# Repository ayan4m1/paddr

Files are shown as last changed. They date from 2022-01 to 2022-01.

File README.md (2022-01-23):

# Paddr

Paddr is a DIY numpad built using [KMK](https://github.com/KMKfw/kmk_firmware). It has four RGB LEDs and seventeen keys.

## Schematic

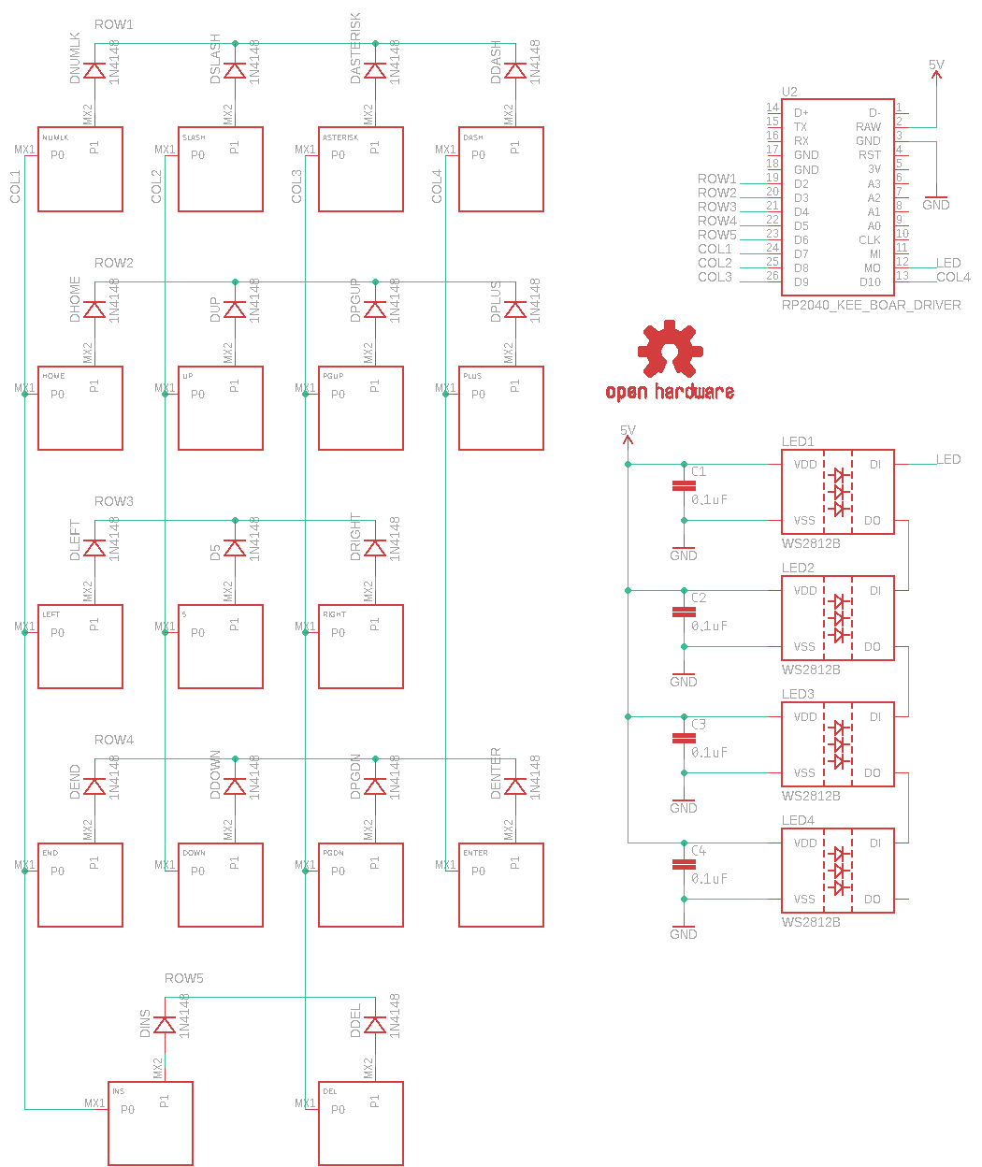
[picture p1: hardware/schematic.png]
schematic


## Board

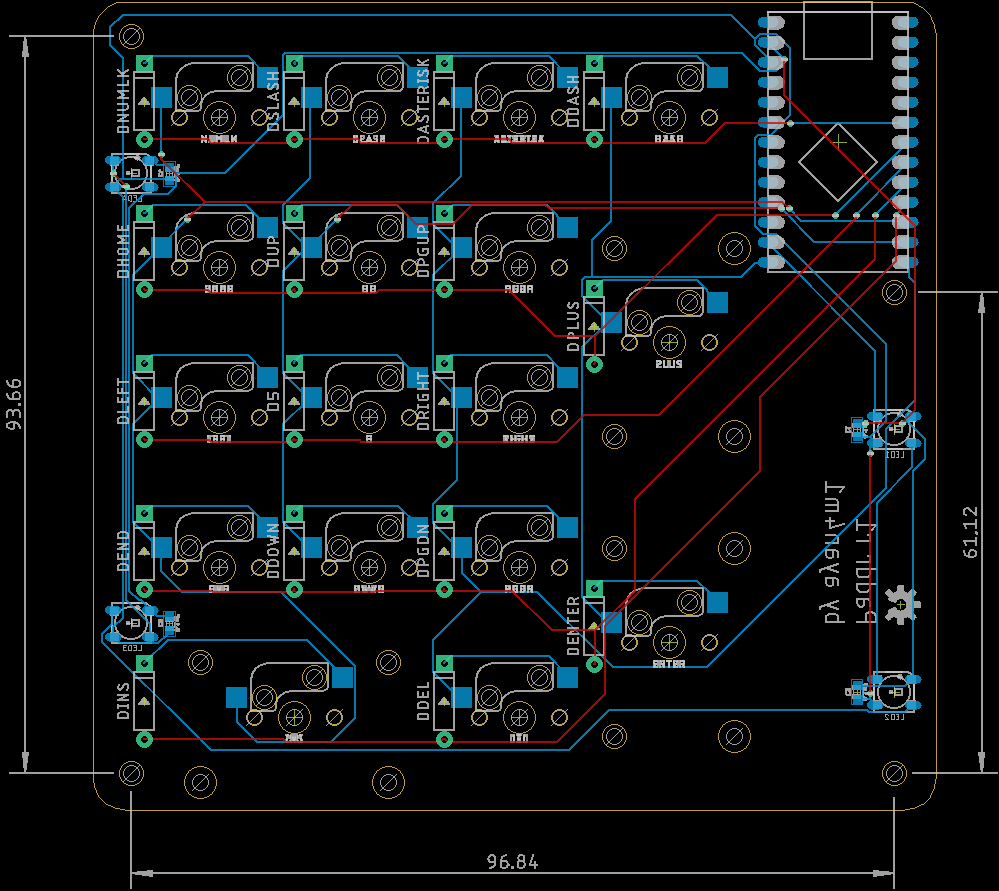
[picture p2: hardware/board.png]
board


## PCB

[OSH Park](https://oshpark.com/shared_projects/GSJlJusC)

## BOM

| Vendor | Part | Quantity |
| --- | --- | --- |
| onsemi | [1N4148 Diode](https://www.mouser.com/ProductDetail/onsemi-Fairchild/1N4148?qs=i4Fj9T%2FoRm8RMUhj5DeFQg%3D%3D) | 17 |
| Kailh | [Hotswap Sockets](https://shop.keyboard.io/products/kailh-hotswap-sockets-for-mx-style-keyswitches-x-25) | 17 |
| Adafruit  | [KB2040](https://www.adafruit.com/product/5302) | 1 |
| Worldsemi | [WS2812B](https://www.adafruit.com/product/1655) | 4 |
| Samsung | [0.1uF 6.3V Capacitor - 0603](https://www.mouser.com/ProductDetail/Samsung-Electro-Mechanics/CL03A105MQ3CSNH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) | 4 |

## Assembly

1. Solder the capacitors and LEDs to the bottom of the board.
2. Solder the hotswap sockets to the bottom of the board.
3. Solder the diodes to the top of the board.
4. Solder the KB2040 to the bottom of the board.

## Firmware

Copy all files from the firmware directory to the root of the CIRCUITPY drive. The keymap lives in code.py.

After you install the firmware, the CIRCUITPY drive and USB serial port will be hidden on subsequent restarts of the numpad. To override this behavior, hold down the dash key while plugging the numpad in.

To configure the RGB, double tap the zero key, then tap one of the following buttons:

| Key | RGB Function |
| --- | --- |
| 5 | Toggle On/Off  |
| 8 | Value Increase |
| 2 | Value Decrease |
| 4 | Hue Decrease |
| 6 | Hue Increase |
| NumLk | Mode - Solid |
| Slash | Mode - Breathe |
| Asterisk | Mode - Rainbow |
| Dash | Mode - Swirl |

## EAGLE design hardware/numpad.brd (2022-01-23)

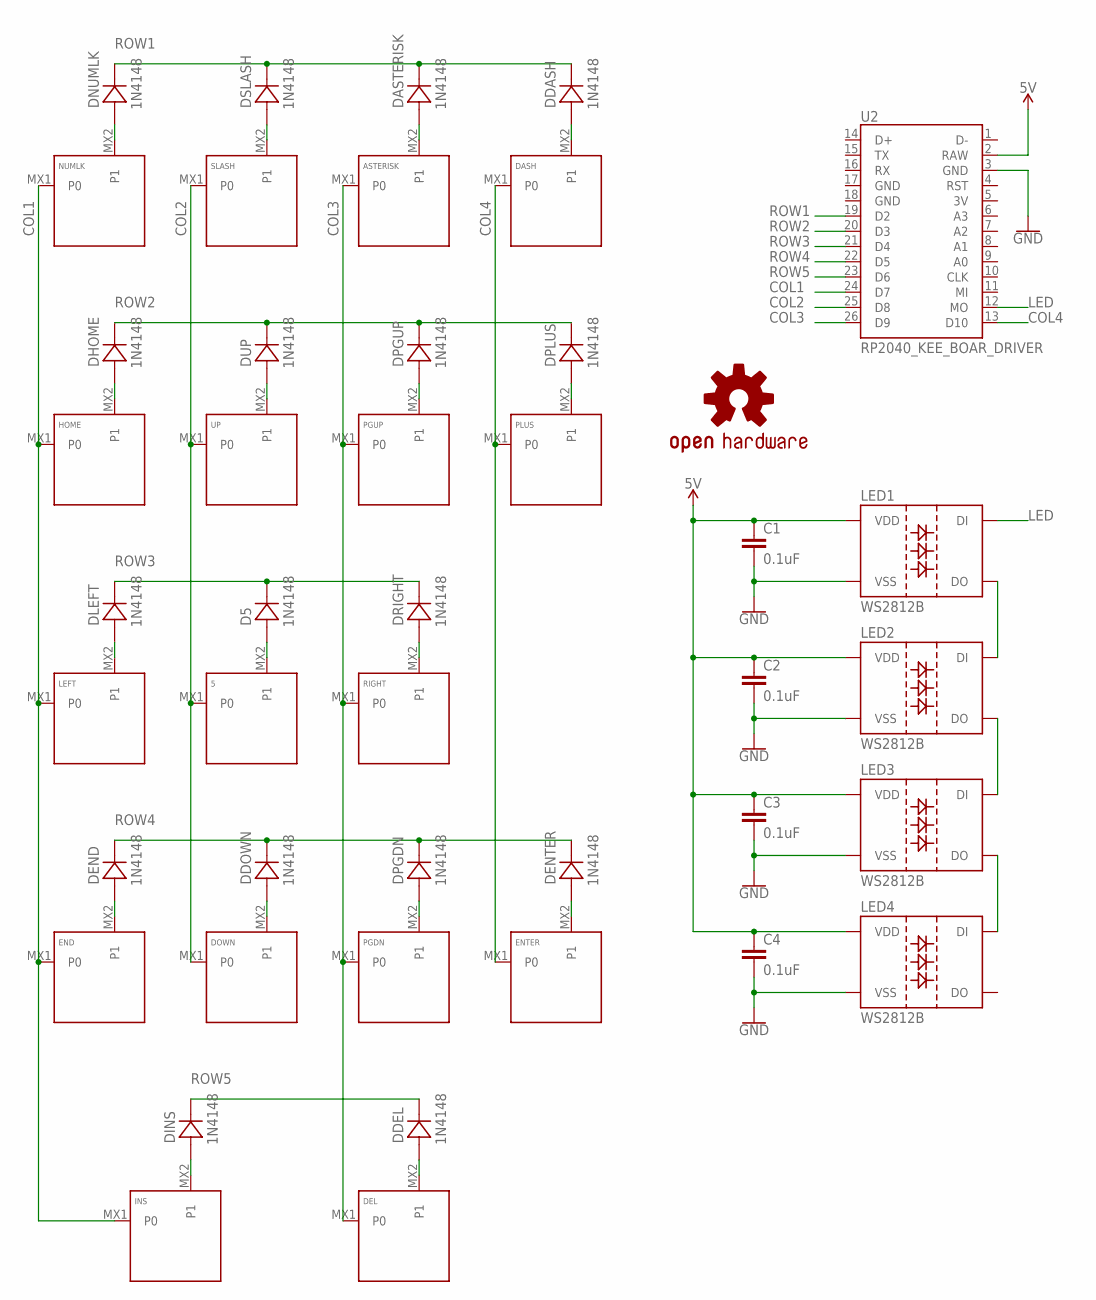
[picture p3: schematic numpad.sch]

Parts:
5: KEYSWITCH-PLAIN-MXHSPCB-1U; MXHSPCB-1U
ASTERISK: KEYSWITCH-PLAIN-MXHSPCB-1U; MXHSPCB-1U
C1, C2, C3, C4: 0.1uF; 0603
D5: 1N4148; DO-35
DASH: KEYSWITCH-PLAIN-MXHSPCB-1U; MXHSPCB-1U
DASTERISK: 1N4148; DO-35
DDASH: 1N4148; DO-35
DDEL: 1N4148; DO-35
DDOWN: 1N4148; DO-35
DEL: KEYSWITCH-PLAIN-MXHSPCB-1U; MXHSPCB-1U
DEND: 1N4148; DO-35
DENTER: 1N4148; DO-35
DHOME: 1N4148; DO-35
DINS: 1N4148; DO-35
DLEFT: 1N4148; DO-35
DNUMLK: 1N4148; DO-35
DOWN: KEYSWITCH-PLAIN-MXHSPCB-1U; MXHSPCB-1U
DPGDN: 1N4148; DO-35
DPGUP: 1N4148; DO-35
DPLUS: 1N4148; DO-35
DRIGHT: 1N4148; DO-35
DSLASH: 1N4148; DO-35
DUP: 1N4148; DO-35
END: KEYSWITCH-PLAIN-MXHSPCB-1U; MXHSPCB-1U
ENTER: KEYSWITCH-PLAIN-MXHSPCB-2U-ROTATED; MXHSPCB-2U-ROTATED
HOME: KEYSWITCH-PLAIN-MXHSPCB-1U; MXHSPCB-1U
INS: KEYSWITCH-PLAIN-MXHSPCB-2U; MXHSPCB-2U
LED1, LED2, LED3, LED4: WS2812B
LEFT: KEYSWITCH-PLAIN-MXHSPCB-1U; MXHSPCB-1U
LOGO1: OSHW-LOGOM; OSHW-LOGO-M
NUMLK: KEYSWITCH-PLAIN-MXHSPCB-1U; MXHSPCB-1U
PGDN: KEYSWITCH-PLAIN-MXHSPCB-1U; MXHSPCB-1U
PGUP: KEYSWITCH-PLAIN-MXHSPCB-1U; MXHSPCB-1U
PLUS: KEYSWITCH-PLAIN-MXHSPCB-2U-ROTATED; MXHSPCB-2U-ROTATED
RIGHT: KEYSWITCH-PLAIN-MXHSPCB-1U; MXHSPCB-1U
SLASH: KEYSWITCH-PLAIN-MXHSPCB-1U; MXHSPCB-1U
U2: RP2040_KEE_BOAR_DRIVER
UP: KEYSWITCH-PLAIN-MXHSPCB-1U; MXHSPCB-1U

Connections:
5V: C1.1, C2.1, C3.1, C4.1, LED1.1 (VDD), LED2.1 (VDD), LED3.1 (VDD), LED4.1 (VDD), U2.2 (RAW)
COL1: END.MX1 (P0), HOME.MX1 (P0), INS.MX1 (P0), LEFT.MX1 (P0), NUMLK.MX1 (P0), U2.24 (D7)
COL2: 5.MX1 (P0), DOWN.MX1 (P0), SLASH.MX1 (P0), U2.25 (D8), UP.MX1 (P0)
COL3: ASTERISK.MX1 (P0), DEL.MX1 (P0), PGDN.MX1 (P0), PGUP.MX1 (P0), RIGHT.MX1 (P0), U2.26 (D9)
COL4: DASH.MX1 (P0), ENTER.MX1 (P0), PLUS.MX1 (P0), U2.13 (D10)
GND: C1.2, C2.2, C3.2, C4.2, LED1.3 (VSS), LED2.3 (VSS), LED3.3 (VSS), LED4.3 (VSS), U2.3 (GND)
LED: LED1.4 (DI), U2.12 (MO)
unnamed: DNUMLK.A, NUMLK.MX2 (P1)
unnamed: DSLASH.A, SLASH.MX2 (P1)
unnamed: ASTERISK.MX2 (P1), DASTERISK.A
unnamed: DASH.MX2 (P1), DDASH.A
unnamed: DHOME.A, HOME.MX2 (P1)
unnamed: DUP.A, UP.MX2 (P1)
unnamed: DPGUP.A, PGUP.MX2 (P1)
unnamed: DPLUS.A, PLUS.MX2 (P1)
unnamed: DLEFT.A, LEFT.MX2 (P1)
unnamed: 5.MX2 (P1), D5.A
unnamed: DRIGHT.A, RIGHT.MX2 (P1)
unnamed: DEND.A, END.MX2 (P1)
unnamed: DDOWN.A, DOWN.MX2 (P1)
unnamed: DPGDN.A, PGDN.MX2 (P1)
unnamed: DENTER.A, ENTER.MX2 (P1)
unnamed: DINS.A, INS.MX2 (P1)
unnamed: DDEL.A, DEL.MX2 (P1)
unnamed: LED1.2 (DO), LED2.4 (DI)
unnamed: LED2.2 (DO), LED3.4 (DI)
unnamed: LED3.2 (DO), LED4.4 (DI)
ROW1: DASTERISK.C, DDASH.C, DNUMLK.C, DSLASH.C, U2.19 (D2)
ROW2: DHOME.C, DPGUP.C, DPLUS.C, DUP.C, U2.20 (D3)
ROW3: D5.C, DLEFT.C, DRIGHT.C, U2.21 (D4)
ROW4: DDOWN.C, DEND.C, DENTER.C, DPGDN.C, U2.22 (D5)
ROW5: DDEL.C, DINS.C, U2.23 (D6)

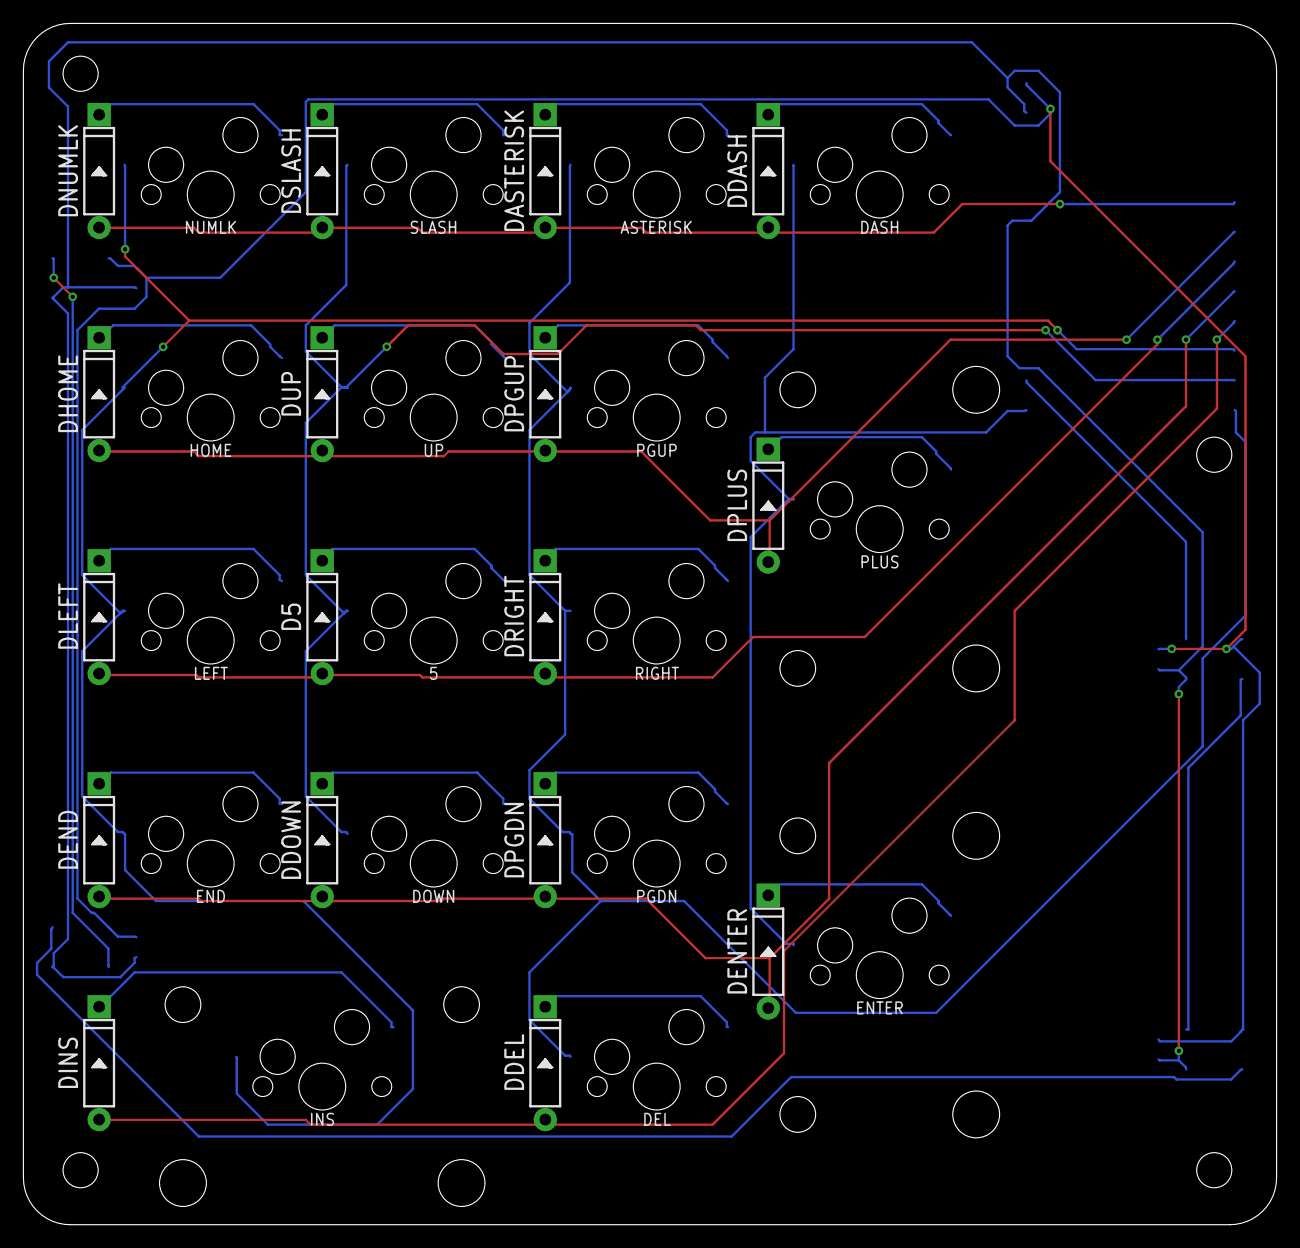
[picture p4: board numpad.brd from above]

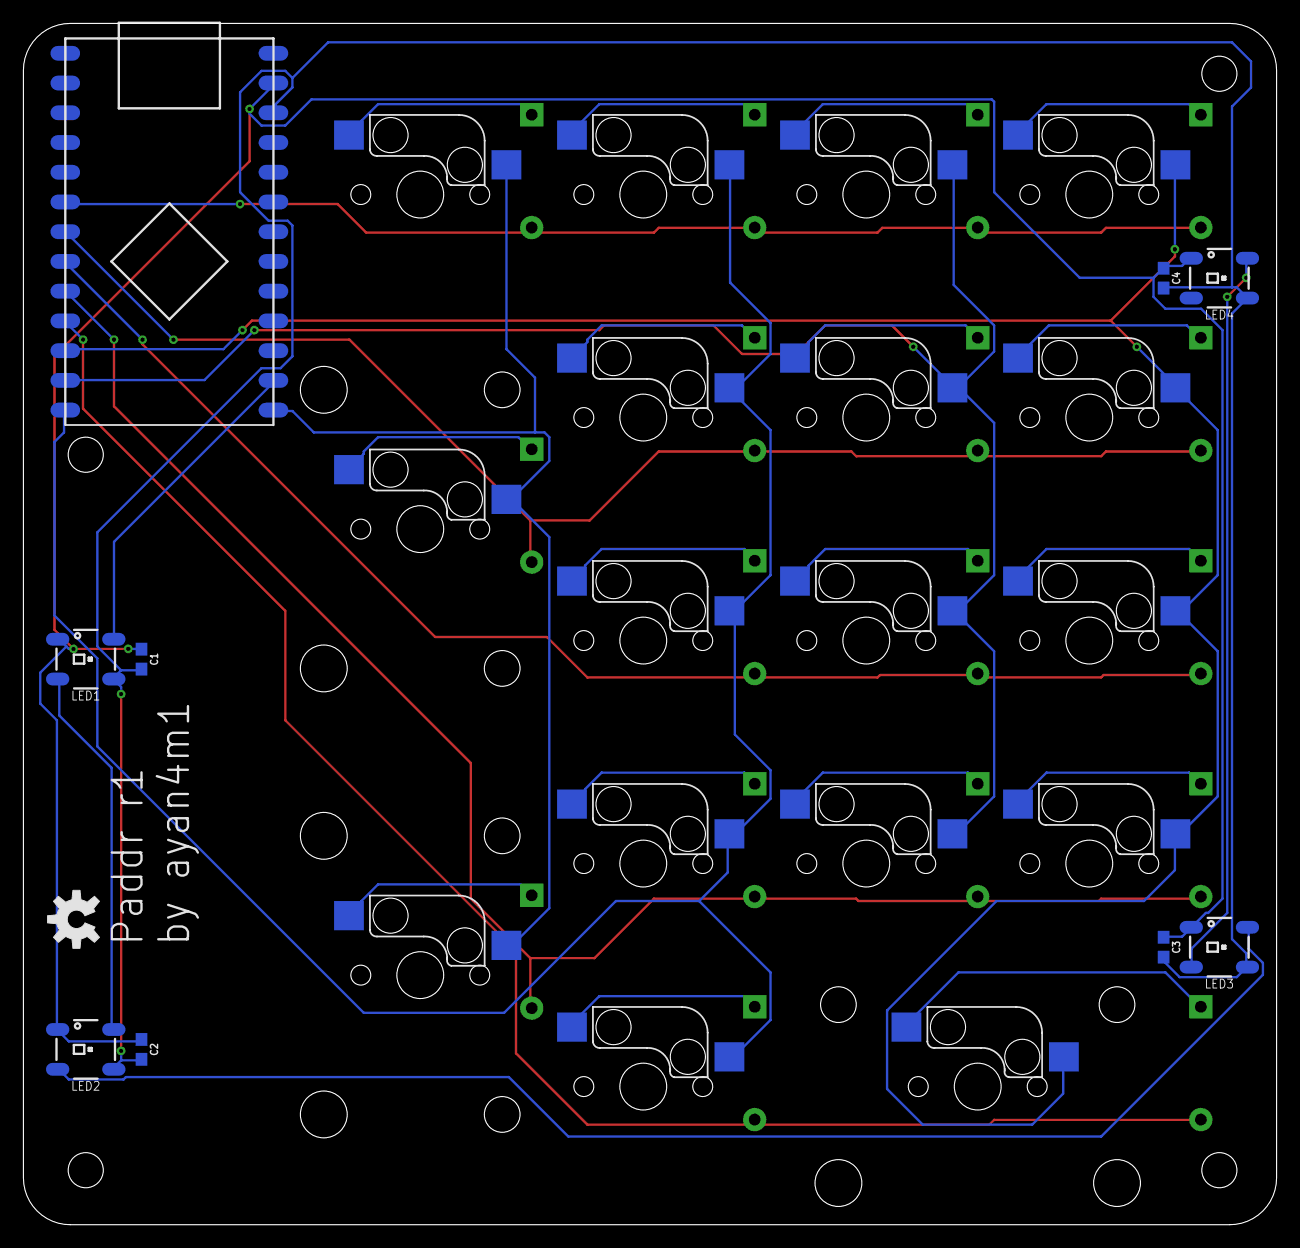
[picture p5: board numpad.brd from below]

Board: 2 copper layers, 107.0 x 102.6 mm, 44 parts (26 on the bottom side), 32 nets.

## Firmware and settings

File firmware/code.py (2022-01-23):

print("Starting")

import board

from kmk.kmk_keyboard import KMKKeyboard
from kmk.keys import KC
from kmk.matrix import DiodeOrientation
from kmk.extensions.RGB import RGB
from kmk.modules.layers import Layers

keyboard = KMKKeyboard()

keyboard.extensions.append(RGB(pixel_pin = board.MOSI, num_pixels = 4))
keyboard.modules.append(Layers())

keyboard.row_pins = (board.D2, board.D3, board.D4, board.D5, board.D6)
keyboard.col_pins = (board.D7, board.D8, board.D9, board.D10)
keyboard.diode_orientation = DiodeOrientation.ROW2COL

RAISE_OR_0 = KC.TD(KC.KP_0, KC.MO(1))

keyboard.keymap = [
    [
        KC.NUMLOCK, KC.KP_SLASH, KC.KP_ASTERISK, KC.KP_MINUS,
        KC.KP_7, KC.KP_8, KC.KP_9, KC.KP_PLUS,
        KC.KP_4, KC.KP_5, KC.KP_6, KC.NO,
        KC.KP_1, KC.KP_2, KC.KP_3, KC.KP_ENTER,
        RAISE_OR_0, KC.KP_DOT, KC.NO, KC.NO
    ],
    [
        KC.RGB_MODE_PLAIN, KC.RGB_MODE_BREATHE, KC.RGB_MODE_RAINBOW, KC.RGB_MODE_SWIRL,
        KC.NO, KC.RGB_VAI, KC.NO, KC.NO,
        KC.RGB_HUI, KC.RGB_TOG, KC.RGB_HUD, KC.NO,
        KC.NO, KC.RGB_VAD, KC.NO, KC.NO,
        KC.NO, KC.NO, KC.NO, KC.NO
    ]
]

keyboard.debug_enabled = False

if __name__ == '__main__':
    print("Executing")
    keyboard.go()

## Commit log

2022-01-23 initial import
    [numpad.brd, numpad.sch]
2022-01-23 add assembly instructions, capacitor to BOM, and RGB config info

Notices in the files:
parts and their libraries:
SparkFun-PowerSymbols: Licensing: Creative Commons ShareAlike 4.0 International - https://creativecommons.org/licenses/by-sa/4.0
